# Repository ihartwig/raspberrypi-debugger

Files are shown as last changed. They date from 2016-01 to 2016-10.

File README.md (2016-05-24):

Raspberry Pi Debugger
=====================

This repository houses bare-metal hardware debugging tools for Raspberry Pi.

debugger2 3D render

## Features

* JTAG, UART, and power for RPi on single USB interface
* Supports Pi 0, 1 (Rev 2), 1+, 2 by breaking away the top section of the board when used with a Pi 1.
* Power control of RPi for system reset from UART (DTR), JTAG (sRST), and physical button
* Does not explode if RPi is powered directly (backpowering the debugger board) or both are powered at the same time independently
* Current measuring by shunt on the RPi 5V supply
* RPi HAT EEPROM footprints available but not populated
* Top SMD only design using the [RPi Foundation example SMT header](https://www.raspberrypi.org/blog/introducing-raspberry-pi-hats/) (optionally can use through hole header soldered later)

## Development Structure

* **config**: configurations for FT_Prog, OpenOCD, and GDB
* **docs**: datasheets and reference schematics this board is based on.
* **debugger**: rev 1 schematic and board in eagle
* **debugger2**: rev 2+ schematic and board in kicad
* **RPiDebuggerVCPBlock**: OS X kernel extension to allow using JTAG with serial

## Support Software

Windows and OS X users need to install the [FTDI VCP drivers](http://www.ftdichip.com/Drivers/VCP.htm). Windows may install it automatically. Linux users can use either the built or FTDI drivers. OS X (10.9+) has basic support for serial with the built in driver but does not trigger the DTR line used to control RPi power.

On OS X the VCP driver will try to assign a serial port to the FTDI channel we want to use for JTAG, preventing us from using JTAG and serial at the same time. We can fix this by installing a dummy kernel module ([suggested resolution from Apple](https://developer.apple.com/library/mac/technotes/tn2315/_index.html)), RPiDebuggerVCPBlock. Download the kext from the [relase page](https://github.com/ihartwig/raspberrypi-debugger/releases) and place it in `/Library/Extensions`. Since the kext is not signed, you must [disable kext certificate checking](http://apple.stackexchange.com/questions/163059/how-can-i-disable-kext-signing-in-mac-os-x-10-10-yosemite) in 10.10+.

To use JTAG on the RPi you need to enable the alternate pin functions in software. This can be done easily by loading the SD card with a dummy kernel that enables the JTAG interface on boot and waits.

## FTDI EEPROM

Newly assembled boards with a blank eeprom should be programmed. Functionally, this tells the windows driver to not open a com port on the FTDI channel we use for JTAG. The templates under `config` can be programmed with [FT_Prog](http://www.ftdichip.com/Support/Utilities.htm#FT_PROG).

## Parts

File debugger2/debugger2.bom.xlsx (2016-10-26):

Source | /Users/ihartwig/repos/raspberrypi-debugger/debugger2/debugger2.sch
Kicad Rev | Eeschema 4.0.0-stable
Generated Date | Wednesday | July 13 | 2016 'AMt' 02:22:38 AM
Title | Raspberry Pi Debugger
Company | Carnegie Mellon University
Revision | 2.1.2
Date Issue | Not Set
Comment | Based on FT2232H Mini Module
Comment | Drawn by: Ian Hartwig
Item # | Reference | Qty | Manufacturer | Mfg Part # | Description | Footprint | Type | Link | Value | Library | Library Ref
1 | C1, C2, C3, C4, C6, C7, C9, C12, C13, C16, C18 | 11 | Murata | GRM188R71C104KA01D | CAP CER 0.1uF ±10% 16V X7R 0603 | Capacitors_SMD:C_0603 | SMT |  | 100n | device | C_Small
2 | C17, C19 | 2 | Murata | GRM1885C1H180JA01D | CAP CER 18PF ±5% 50V NP0 0603 | Capacitors_SMD:C_0603 | SMT |  | 18pF | device | C_Small
3 | C20, C21 | 2 | Murata | GRM188R71C105KE15D | CAP CER 1UF ±10% 16V X7R 0603 | Capacitors_SMD:C_0603 | SMT |  | 1uF | device | C_Small
4 | C22 | 1 | Murata | GRM188R71C104KA01D | CAP CER 0.1uF ±10% 16V X7R 0603 | Capacitors_SMD:C_0603 | DNS |  | dnp-100n | device | C_Small
5 | C5, C8, C11, C14, C15 | 5 | AVX | 1206YG475ZAT2A | CAP CER 4.7UF -20% ~ + 80% 16V Y5V 1206 | Capacitors_SMD:C_1206 | SMT |  | 4.7u | device | CP1_Small
6 | D1, D2, D3 | 3 | Lite-On | LTST-C190GKT | LED GREEN CLEAR 0603 SMD | LEDs:LED-0603 | SMT | http://www.digikey.com/product-detail/en/LTST-C190GKT/160-1183-1-ND/269255 | RXLED | device | Led_Small
7 | D4, D5 | 2 | Panasonic | DB2S20500L | DIODE SCHOTTKY 15V 200MA SSMINI2 | Diodes_SMD:SOD-523 | SMT | http://www.digikey.com/product-detail/en/panasonic-electronic-components/DB2S20500L/DB2S20500LCT-ND/2326091 | D_Small | device | D_Small
8 | FB1, FB2 | 2 | Samsung | CIM21J202NE | FERRITE BEAD 2 KOHM 0805 | Resistors_SMD:R_0805 | SMT | http://www.digikey.com/product-detail/en/CIM21J202NE/1276-6330-1-ND/3973845 | 600R/0.5A | device | L_Small
9 | P1 | 1 |  |  |  | Pin_Headers:Pin_Header_Straight_1x02 | DNS |  | CONN_01X01 | conn | CONN_01X01
10 | P3 | 1 | Amphenol-FCI | 10118192-0001LF | USB - micro B USB 2.0 Receptacle Connector 5 Position Surface Mount, Right Angle, Horizontal | debugger2-special:USB_Micro-B_SMT | SMT | http://www.digikey.com/product-detail/en/amphenol-fci/10118192-0001LF/609-4613-1-ND/2785378 | USB_OTG | conn | USB_OTG
11 | P4 | 1 | Samtec | REF-182665-01 | 2x20 pos. with PCB alignment peg option | debugger2-special:Pin_Header_Straight_TH-SMT_2x20 | DNS | http://www.toby.co.uk/content/catalogue/products.aspx?series=REF-1826xx-0x | CONN_02X20 | conn | CONN_02X20 | Can also use Harwin M20-6102045 (Digikey 952-2219-ND) for bottom TH.
12 | P5 | 1 |  |  |  | Pin_Headers:Pin_Header_Straight_1x02 | DNS |  | dnp-CONN_01X02 | conn | CONN_01X02
13 | Q1 | 1 | Diodes Inc | DMP3099L-7 | MOSFET P-CH 30V SOT23 | TO_SOT_Packages_SMD:SOT-23 | SMT | http://www.digikey.com/product-detail/en/DMP3099L-7/DMP3099L-7DICT-ND/5218217 | Q_PMOS_GSD | device | Q_PMOS_GSD
14 | Q2 | 1 | Diodes Inc | DMMT3906-7-F | TRANS 2PNP 40V 0.2A SOT26 | TO_SOT_Packages_SMD:SOT-23-6 | SMT | http://www.digikey.com/product-detail/en/DMMT3906-7-F/DMMT3906-7-FDICT-ND/2242785 | DMMT3906_Dual_PNP | debugger2-special | DMMT3906_Dual_PNP
15 | R1, R6, R8, R13, R19 | 5 | Vishay Dale | CRCW060310K0FKEA | RES SMD 10K OHM 1% 1/10W 0603 | Resistors_SMD:R_0603 | SMT |  | 10k | device | R_Small
16 | R11, R12 | 2 | Vishay Dale | CRCW060310R0FKEA | RES SMD 10 OHM 1% 1/10W 0603 | Resistors_SMD:R_0603 | SMT |  | 10 | device | R
17 | R14 | 1 | Vishay Dale | CRCW060347K0FKEA | RES SMD 47K OHM 1% 1/10W 0603 | Resistors_SMD:R_0603 | SMT | http://www.digikey.com/product-detail/en/vishay-dale/CRCW060347K0FKEA/541-47.0KHCT-ND/1180000 | 47k | device | R_Small
18 | R16 | 1 | Vishay Dale | CRCW06031K00FKEA | RES SMD 1K OHM 1% 1/10W 0603 | Resistors_SMD:R_0603 | DNS |  | dnp-1k | device | R_Small
19 | R17, R18 | 2 | Vishay Dale | CRCW06033K90FKEA | RES SMD 3.9K OHM 1% 1/10W 0603 | Resistors_SMD:R_0603 | DNS |  | dnp-3.9k | device | R_Small
20 | R2 | 1 | Vishay Dale | CRCW06032K00FKEA | RES SMD 2K OHM 1% 1/10W 0603 | Resistors_SMD:R_0603 | SMT |  | 2k | device | R_Small
21 | R3 | 1 | Vishay Dale | CRCW060320K0FKEA | RES SMD 20K OHM 1% 1/10W 0603 | Resistors_SMD:R_0603 | SMT |  | 20k | device | R_Small
22 | R4 | 1 | Vishay Dale | CRCW060333K0FKEA | RES SMD 33K OHM 1% 1/10W 0603 | Resistors_SMD:R_0603 | SMT |  | 33k | device | R_Small
23 | R5 | 1 |  |  |  | Resistors_SMD:R_0603 | DNS |  | dnp-0 | device | R
24 | R7 | 1 | Stackpole Electronics | CSR1206FT50L0 | RES SMD 0.05 OHM 1% 1/2W 1206 | Resistors_SMD:R_1206 | SMT | http://www.digikey.com/product-detail/en/stackpole-electronics-inc/CSR1206FT50L0/CSR1206FT50L0CT-ND/3477072 | 0.01 | device | R
25 | R9, R10, R15 | 3 | Vishay Dale | CRCW0603220RFKEA | RES SMD 220 OHM 1% 1/10W 0603 | Resistors_SMD:R_0603 | SMT | http://www.digikey.com/product-detail/en/vishay-dale/CRCW0603220RFKEA/541-220HCT-ND/1179731 | 220 | device | R_Small
26 | SW1 | 1 | TE Connectivity | FSMCTTR | SWITCH TACTILE SPST-NO 0.02A 15V | Buttons_Switches_SMD:SW_SPST_EVPBF | SMT | http://www.digikey.com/product-detail/en/FSMCTTR/450-2133-1-ND/5343813 | SW_PUSH | device | SW_PUSH
27 | U1 | 1 | Microchip | 93LC56B-I/ST | IC EEPROM 2KBIT 2MHZ 8TSSOP | Housings_SSOP:TSSOP-8_4.4x3mm_Pitch0.65mm | SMT | http://www.digikey.com/product-detail/en/93LC56B-I%2FST/93LC56B-I%2FST-ND/319187 | 93LC56B | memory | 93LCxxA
28 | U2 | 1 | Microchip | MIC94092YC6-TR | IC LOAD SW HGH SIDE 1.2A SC70-6 | TO_SOT_Packages_SMD:SC-70-6 | SMT | http://www.digikey.com/product-detail/en/microchip-technology/MIC94092YC6-TR/576-3488-1-ND/2062485 | MIC94092_SC-70 | debugger2-special | MIC94092_SC-70
29 | U3 | 1 | FTDI | FT2232HL | IC USB HS DUAL UART/FIFO 64-LQFP | Housings_QFP:TQFP-64_10x10mm_Pitch0.5mm | SMT | http://www.digikey.com/product-detail/en/FT2232HL-REEL/768-1024-1-ND/1986057 | FT2232HL | debugger2-special | FT2232HL
30 | U4 | 1 | Diodes Inc | AP7365-33WG-7 | IC REG LDO 3.3V 0.6A SOT-25 | TO_SOT_Packages_SMD:SOT-23-5 | SMT | http://www.digikey.com/product-detail/en/AP7365-33WG-7/AP7365-33WG-7DICT-ND/5267107 | AP7365_SOT-23-5 | debugger2-special | AP7365_SOT-23-5
31 | U5 | 1 | NXP | PRTR5V0U2X,215 | TVS DIODE 5.5VWM SOT143B | debugger2-special:SOT-143_NXP | SMT | http://www.digikey.com/product-detail/en/PRTR5V0U2X,215/568-4140-1-ND/1589981 | PRTR5V0U2X | debugger2-special | PRTR5V0U2X
32 | U6 | 1 |  |  |  | Housings_SSOP:TSSOP-8_4.4x3mm_Pitch0.65mm | DNS |  | dnp-AT24CS32-SSHM | memory | AT24CS32-SSHM
33 | Y1 | 1 | Abracon LLC | ABM8-12.000MHZ-B2-T | 12MHz ±20ppm Crystal 18pF 120 Ohm -20°C ~ 70°C Surface Mount 4-SMD, No Lead (DFN, LCC) | debugger2-special:Crystal_Grounded_3.2x2.5 | SMT | http://www.digikey.com/product-detail/en/ABM8-12.000MHZ-B2-T/535-9826-1-ND/2001449 | 12MHz | device | CRYSTAL_SMD

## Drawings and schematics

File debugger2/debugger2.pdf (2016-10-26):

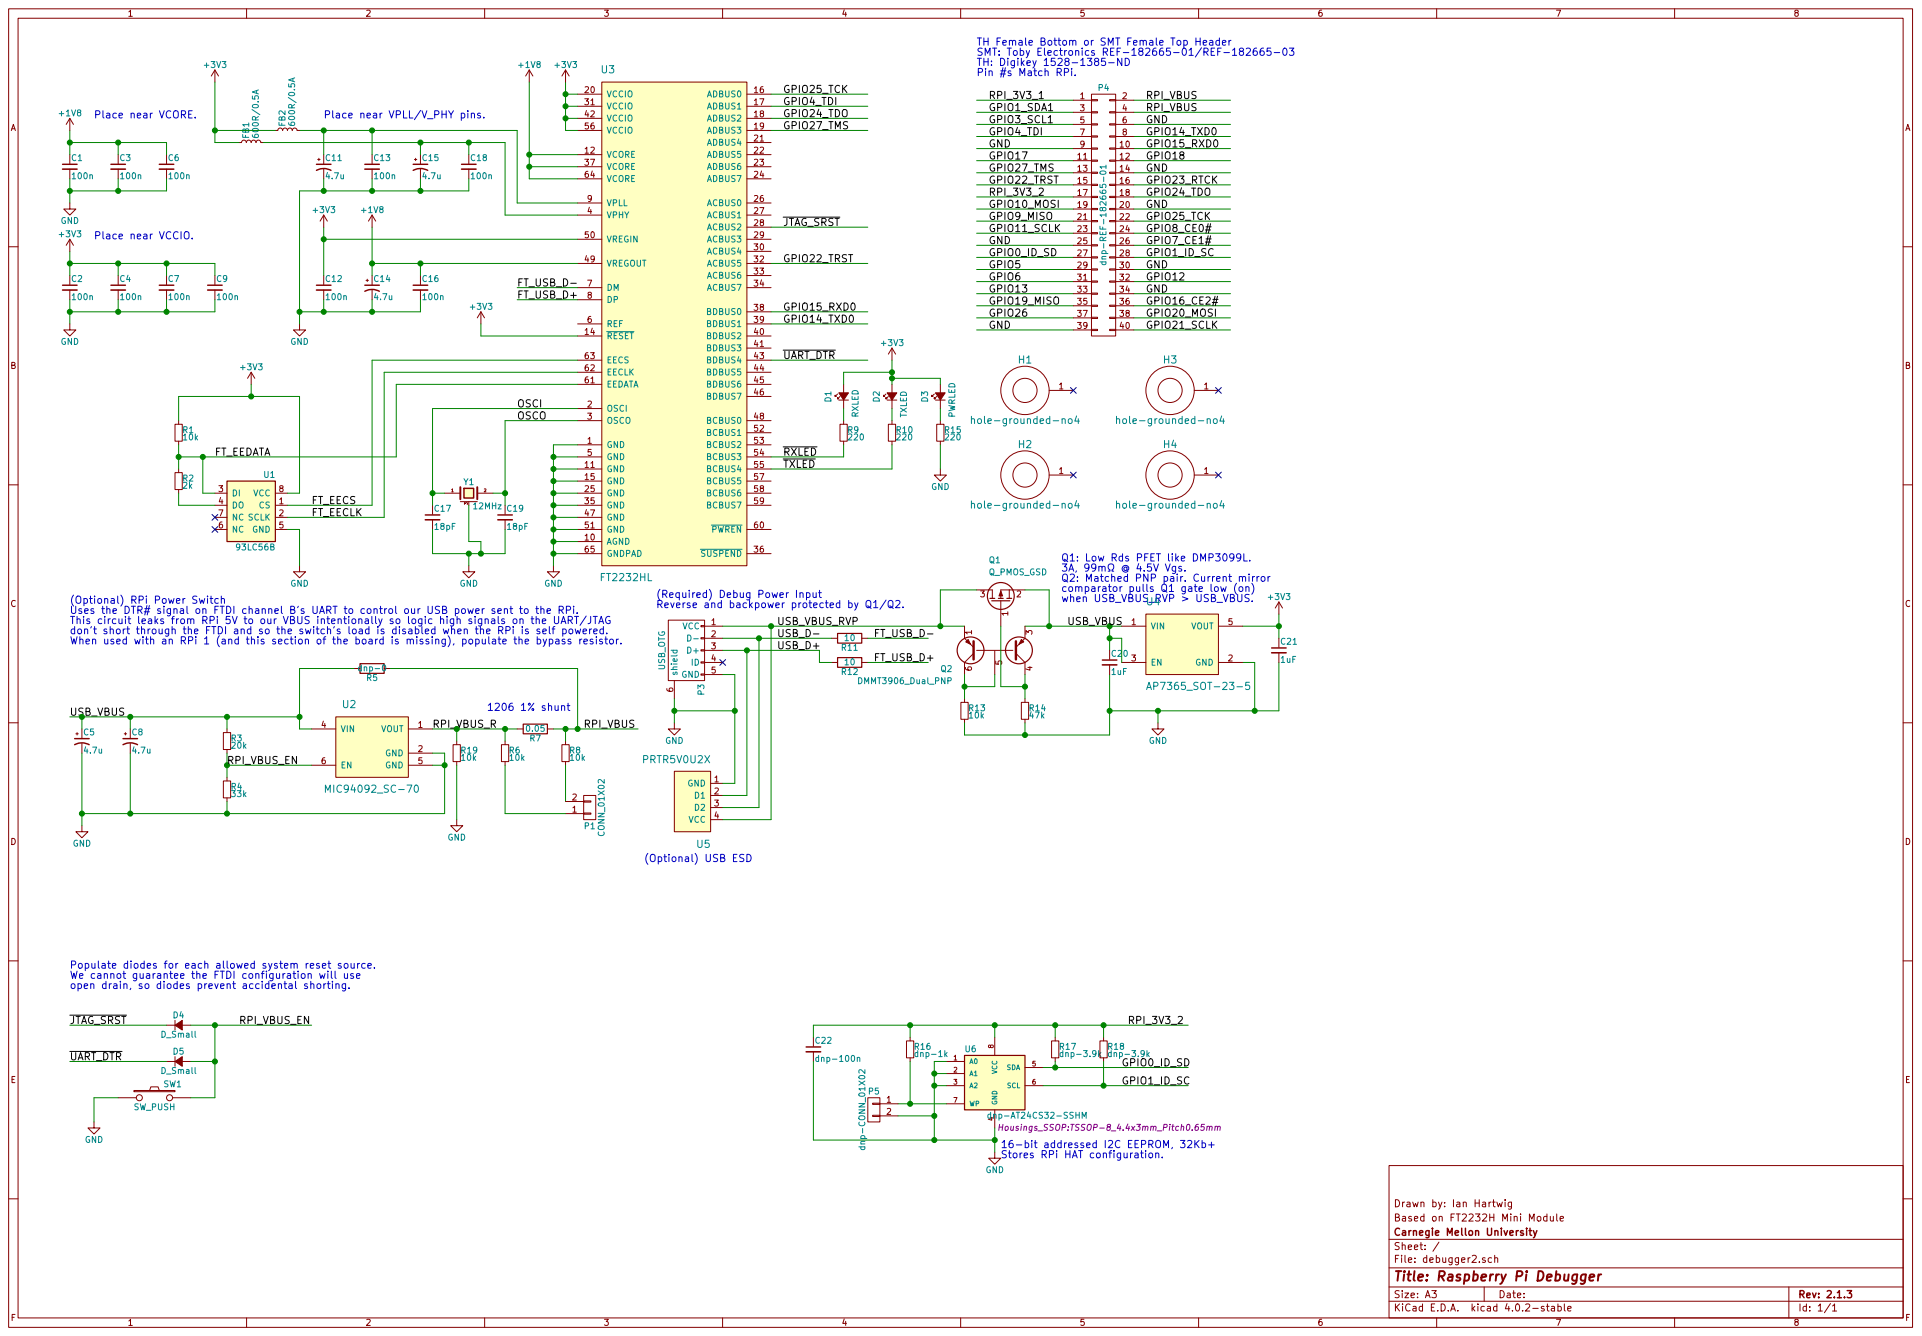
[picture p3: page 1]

TH Female Bottom or SMT Female Top Header
SMT: Toby Electronics REF-182665-01/REF-182665-03
TH: Digikey 1528-1385-ND

GPIO4_TDI
GPIO24_TDO
GPIO27_TMS

When used with an RPi 1 (and this section of the board is missing), populate the bypass resistor. R1

Q1: Low Rds PFET like DMP3099L.
3A, 99m @ 4.5V Vgs.
Q2: Matched PNP pair. Current mirror
comparator pulls Q1 gate low (on)

(Optional) RPi Power Switch
Uses the DTR# signal on FTDI channel B's UART to control our USB power sent to the RPi.
This circuit leaks from RPi 5V to our VBUS intentionally so logic high signals on the UART/JTAG
don't short through the FTDI and so the switch's load is disabled when the RPi is self powered.

(Required) Debug Power Input
Reverse and backpower protected by Q1/Q2.

Populate diodes for each allowed system reset source.
We cannot guarantee the FTDI configuration will use

File: debugger2.sch Sheet: / Carnegie Mellon University Based on FT2232H Mini Module Drawn by: Ian Hartwig

Id: 1/1 Title: Raspberry Pi Debugger

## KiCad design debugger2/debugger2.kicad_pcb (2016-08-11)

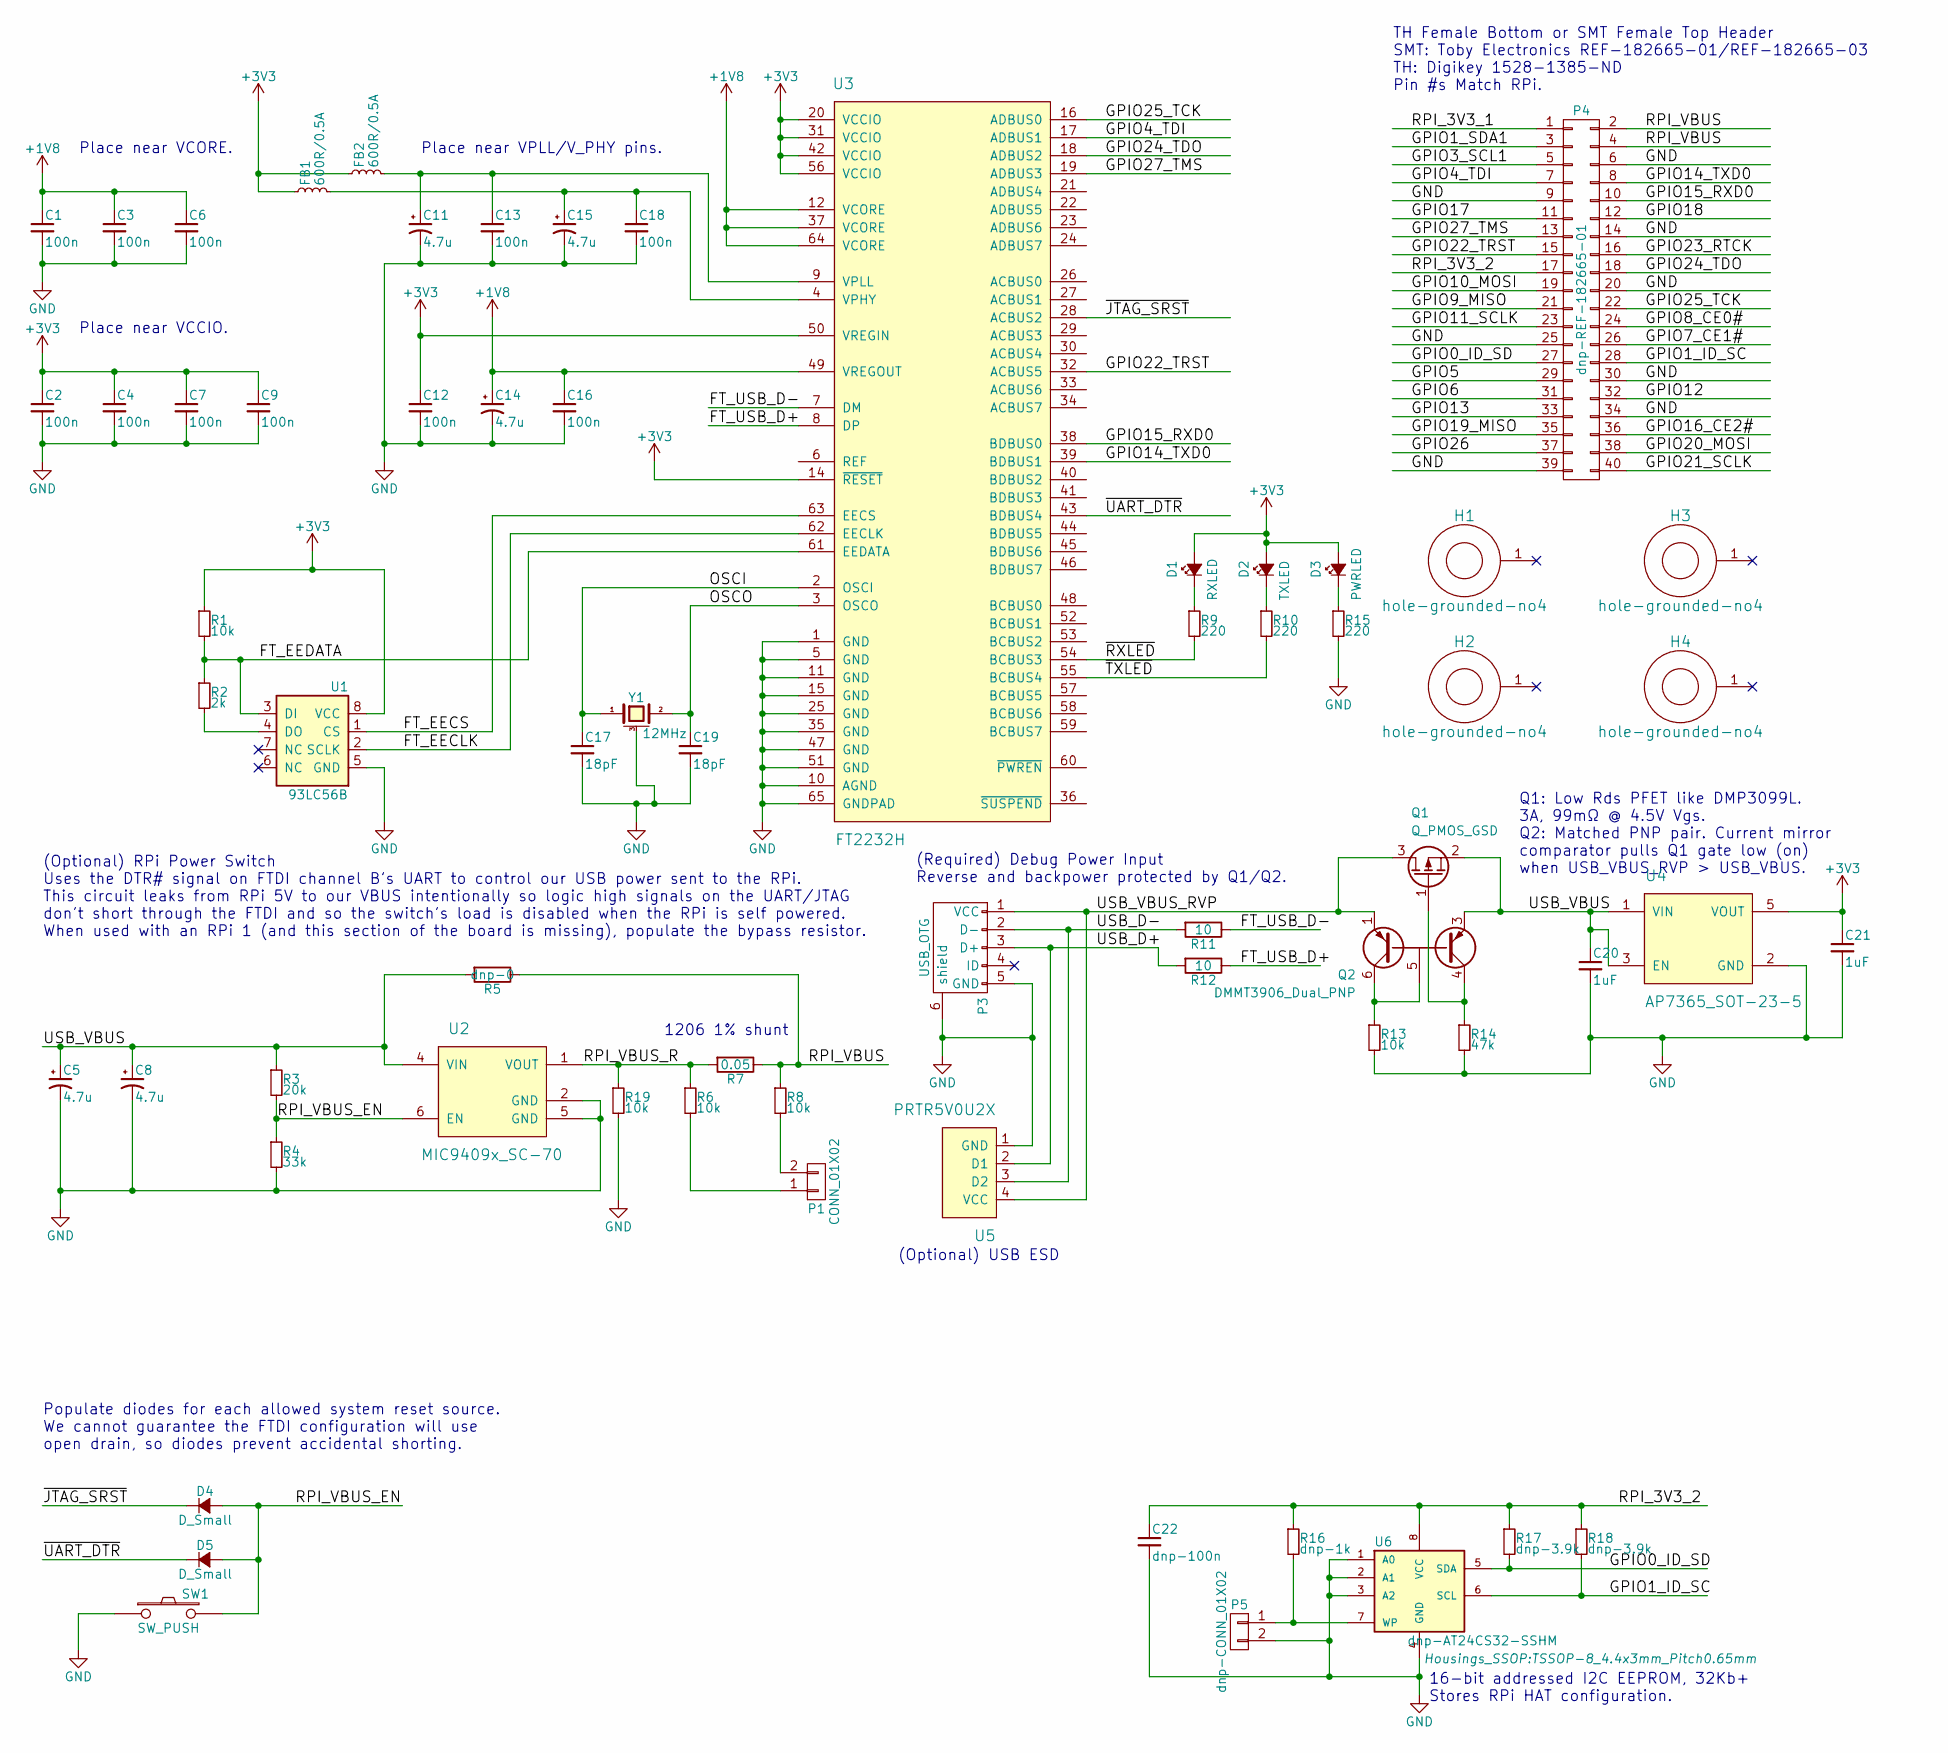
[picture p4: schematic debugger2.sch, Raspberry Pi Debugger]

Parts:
C1, C2, C3, C4, C6, C7, C9, C12, C13, C16, C18: 100n; C_0603
C5, C8, C11, C14, C15: 4.7u; C_1206
C17, C19: 18pF; C_0603
C20, C21: 1uF; C_0603
C22: dnp-100n; C_0603
D1: RXLED; LED-0603
D2: TXLED; LED-0603
D3: PWRLED; LED-0603
D4, D5: D_Small; SOD-523
FB1, FB2: 600R/0.5A; R_0805
H1, H2, H3, H4: hole-grounded-no4; hole-no4
P1: CONN_01X02; Pin_Header_Straight_1x02
P3: USB_OTG; USB_Micro-B_SMT
P4: dnp-REF-182665-01; Pin_Header_Straight_TH-SMT-NoPaste_2x20
P5: dnp-CONN_01X02; Pin_Header_Straight_1x02
Q1: Q_PMOS_GSD; SOT-23
Q2: DMMT3906_Dual_PNP; SOT-23-6
R1, R6, R8, R13, R19: 10k; R_0603
R2: 2k; R_0603
R3: 20k; R_0603
R4: 33k; R_0603
R5: dnp-0; R_0603
R7: 0.05; R_1206
R9, R10, R15: 220; R_0603
R11, R12: 10; R_0603
R14: 47k; R_0603
R16: dnp-1k; R_0603
R17, R18: dnp-3.9k; R_0603
SW1: SW_PUSH; SW_SPST_EVPBF
U1: 93LC56B; TSSOP-8_4.4x3mm_Pitch0.65mm
U2: MIC9409x_SC-70; SC-70-6
U3: FT2232H; TQFP-64_10x10mm_Pitch0.5mm
U4: AP7365_SOT-23-5; SOT-23-5
U5: PRTR5V0U2X; SOT-143_NXP
U6: dnp-AT24CS32-SSHM; TSSOP-8_4.4x3mm_Pitch0.65mm
Y1: 12MHz; Crystal_Grounded_3.2x2.5

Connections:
+1V8: C1.1, C3.1, C6.1, C14.1, C16.1, U3.12 (VCORE), U3.37 (VCORE), U3.49 (VREGOUT), U3.64 (VCORE)
+3V3: C2.1, C4.1, C7.1, C9.1, C12.1, C21.1, D1.2 (A), D2.2 (A), D3.2 (A), FB1.1, FB2.1, R1.1, U1.8 (VCC), U3.14 (~RESET), U3.20 (VCCIO), U3.31 (VCCIO), U3.42 (VCCIO), U3.50 (VREGIN), U3.56 (VCCIO), U4.5 (VOUT)
/FT_EECLK: U1.2 (SCLK), U3.62 (EECLK)
/FT_EECS: U1.1 (CS), U3.63 (EECS)
/FT_EEDATA: R1.2, R2.1, U1.3 (DI), U3.61 (EEDATA)
/FT_USB_D+: R12.1, U3.8 (DP)
/FT_USB_D-: R11.1, U3.7 (DM)
/GPIO0_ID_SD: P4.27, R17.2, U6.5 (SDA)
/GPIO1_ID_SC: P4.28, R18.2, U6.6 (SCL)
/GPIO1_SDA1: P4.3
/GPIO3_SCL1: P4.5
/GPIO4_TDI: P4.7, U3.17 (ADBUS1)
/GPIO5: P4.29
/GPIO6: P4.31
/GPIO7_CE1#: P4.26
/GPIO8_CE0#: P4.24
/GPIO9_MISO: P4.21
/GPIO10_MOSI: P4.19
/GPIO11_SCLK: P4.23
/GPIO12: P4.32
/GPIO13: P4.33
/GPIO14_TXD0: P4.8, U3.39 (BDBUS1)
/GPIO15_RXD0: P4.10, U3.38 (BDBUS0)
/GPIO16_CE2#: P4.36
/GPIO17: P4.11
/GPIO18: P4.12
/GPIO19_MISO: P4.35
/GPIO20_MOSI: P4.38
/GPIO21_SCLK: P4.40
/GPIO22_TRST: P4.15, U3.32 (ACBUS5)
/GPIO23_RTCK: P4.16
/GPIO24_TDO: P4.18, U3.18 (ADBUS2)
/GPIO25_TCK: P4.22, U3.16 (ADBUS0)
/GPIO26: P4.37
/GPIO27_TMS: P4.13, U3.19 (ADBUS3)
/OSCI: C17.1, U3.2 (OSCI), Y1.1
/OSCO: C19.1, U3.3 (OSCO), Y1.2
/RPI_3V3_1: P4.1
/RPI_3V3_2: C22.1, P4.17, R16.1, R17.1, R18.1, U6.8 (VCC)
/RPI_VBUS: P4.2, P4.4, R5.1, R7.1, R8.1
/RPI_VBUS_EN: D4.2 (A), D5.2 (A), R3.2, R4.1, SW1.2, U2.6 (EN)
/RPI_VBUS_R: R6.1, R7.2, R19.1, U2.1 (VOUT)
/USB_D+: P3.3 (D+), R12.2, U5.2 (D1)
/USB_D-: P3.2 (D-), R11.2, U5.3 (D2)
/USB_VBUS: C5.1, C8.1, C20.1, Q1.2 (S), Q2.3 (E2), R3.1, R5.2, U2.4 (VIN), U4.1 (VIN), U4.3 (EN)
/USB_VBUS_RVP: P3.1 (VCC), Q1.3 (D), Q2.1 (E1), U5.4 (VCC)
/~JTAG_SRST: D4.1 (K), U3.28 (ACBUS2)
/~RXLED: R9.2, U3.54 (BCBUS3)
/~TXLED: R10.2, U3.55 (BCBUS4)
/~UART_DTR: D5.1 (K), U3.43 (BDBUS4)
GND: C1.2, C2.2, C3.2, C4.2, C5.2, C6.2, C7.2, C8.2, C9.2, C11.2, C12.2, C13.2, C14.2, C15.2, C16.2, C17.2, C18.2, C19.2, C20.2, C21.2, C22.2, P3.5 (GND), P3.6 (shield), P4.6, P4.9, P4.14, P4.20, P4.25, P4.30, P4.34, P4.39, P5.2, R4.2, R13.2, R14.2, R15.2, R19.2, SW1.1, U1.5 (GND), U2.2 (GND), U2.5 (GND), U3.1 (GND), U3.5 (GND), U3.10 (AGND), U3.11 (GND), U3.15 (GND), U3.25 (GND), U3.35 (GND), U3.47 (GND), U3.51 (GND), U3.65 (GNDPAD), U4.2 (GND), U5.1 (GND), U6.1 (A0), U6.2 (A1), U6.3 (A2), U6.4 (GND), Y1.3 (case)
unnamed: C11.1, C13.1, FB2.2, U3.9 (VPLL)
unnamed: C15.1, C18.1, FB1.2, U3.4 (VPHY)
unnamed: D1.1 (K), R9.1
unnamed: D2.1 (K), R10.1
unnamed: D3.1 (K), R15.1
unnamed: P1.1, R6.2
unnamed: P1.2, R8.2
unnamed: P5.1, R16.2, U6.7 (WP)
unnamed: Q1.1 (G), Q2.4 (C2), R14.1
unnamed: Q2.5 (B), Q2.6 (C1), R13.1
unnamed: R2.2, U1.4 (DO)

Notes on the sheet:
Place near VCCIO.
Place near VCORE.
(Optional) RPi Power Switch Uses the DTR# signal on FTDI channel B's UART to control our USB power sent to the RPi. This circuit leaks from RPi 5V to our VBUS intentionally so logic high signals on the UART/JTAG don't short through the FTDI and so the switch's load is disabled when the RPi is self 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
TH Female Bottom or SMT Female Top Header SMT: Toby Electronics REF-182665-01/REF-182665-03 TH: Digikey 1528-1385-ND Pin #s Match RPi.
1206 1% shunt
(Required) Debug Power Input Reverse and backpower protected by Q1/Q2.
Q1: Low Rds PFET like DMP3099L. 3A, 99mΩ @ 4.5V Vgs. Q2: Matched PNP pair. Current mirror comparator pulls Q1 gate low (on) when USB_VBUS_RVP > USB_VBUS.
Place near VPLL/V_PHY pins.
(Optional) USB ESD
16-bit addressed I2C EEPROM, 32Kb+ Stores RPi HAT configuration.
Populate diodes for each allowed system reset source. We cannot guarantee the FTDI configuration will use open drain, so diodes prevent accidental shorting.

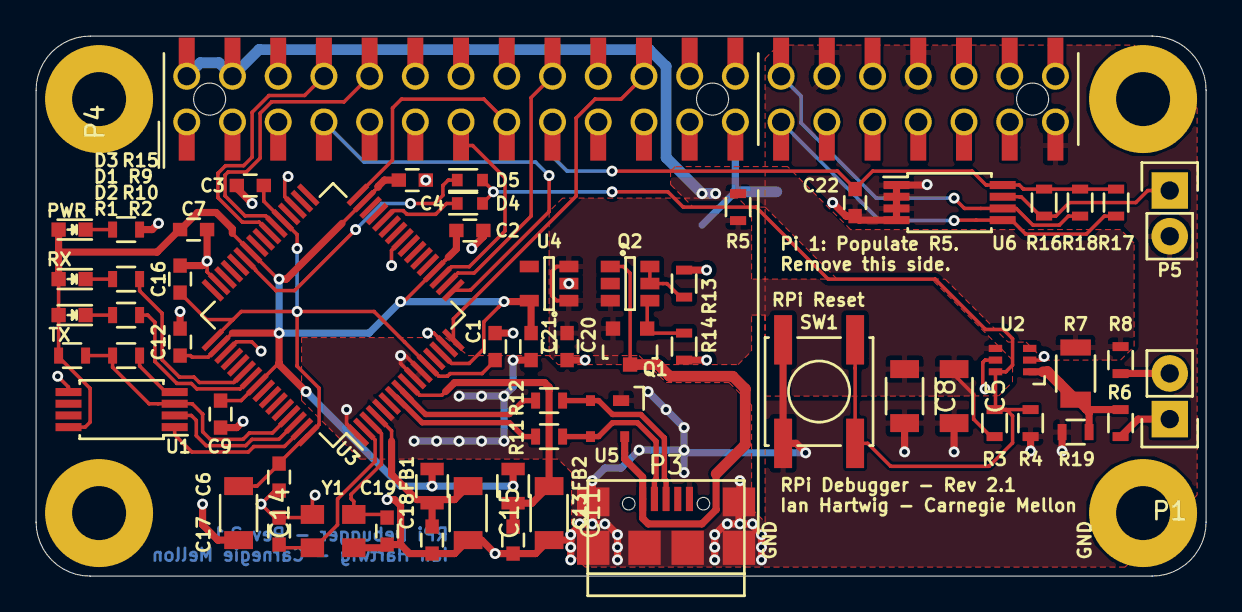
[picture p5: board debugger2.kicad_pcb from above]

Board: 2 copper layers, 65.0 x 30.0 mm, 65 parts (0 on the bottom side), 42 nets.

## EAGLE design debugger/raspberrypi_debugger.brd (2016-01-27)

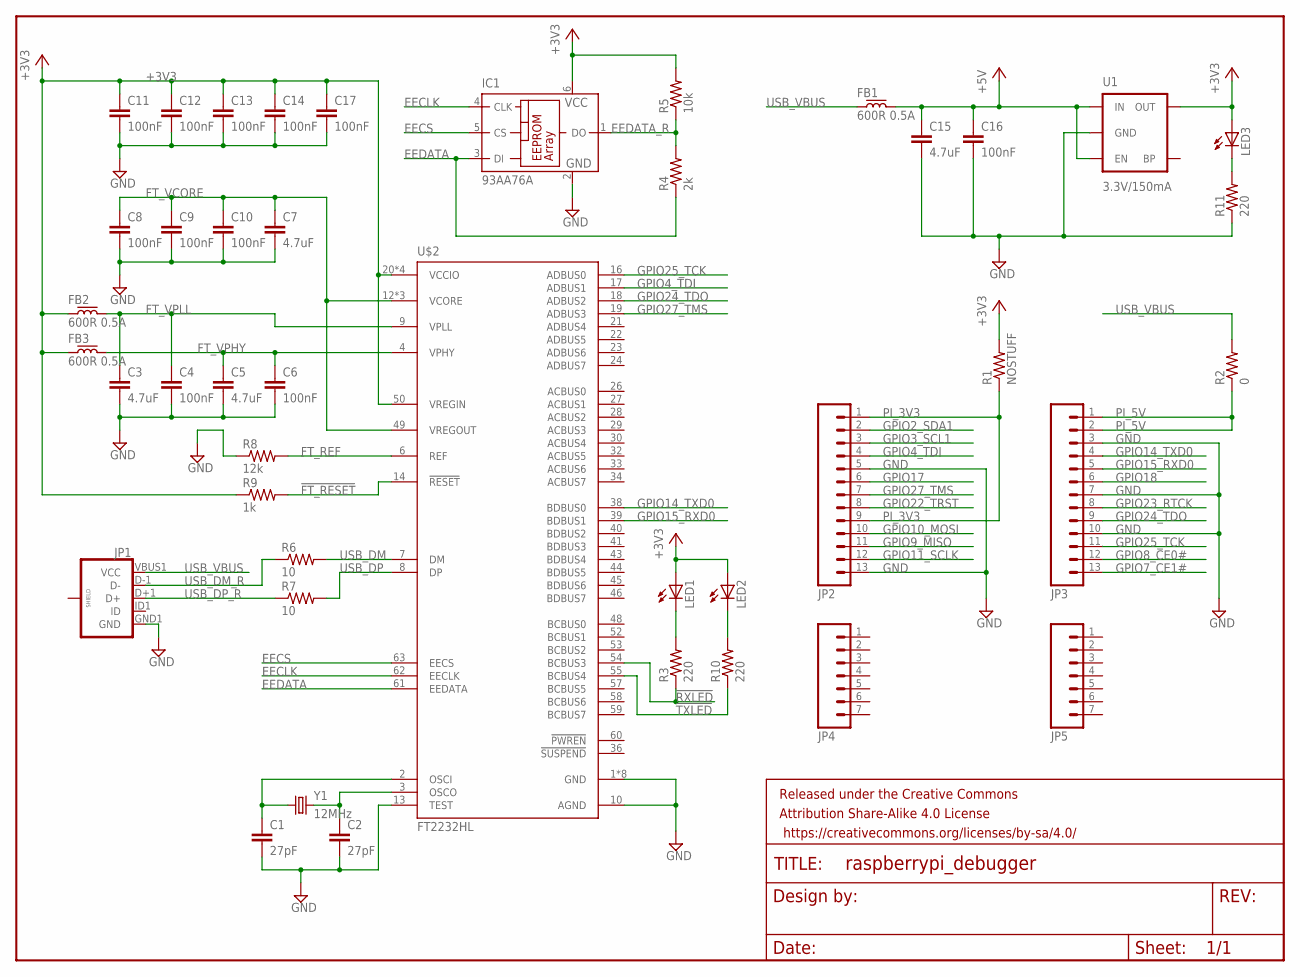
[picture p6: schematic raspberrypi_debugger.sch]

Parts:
C1, C2: 27pF; C0805
C3, C5, C7, C15: 4.7uF; C1206
C4, C6, C8, C9, C10, C11, C12, C13, C14, C16, C17: 100nF; C0805
FB1, FB2, FB3: 600R 0.5A; R0805
FRAME1: FRAME-LETTERNO_PACKAGE; DUMMY
IC1: 93AA76A; SOT23-6
JP1: USB_MICROB_PLUGCONN-11752; USB-B-MICRO-SMD_V03
JP2, JP3: M13LOCK; 1X13_LOCK
JP4, JP5: M07LOCK; 1X07_LOCK
LED1, LED2, LED3: LEDCHIP-LED0805; CHIP-LED0805
R1: NOSTUFF; R0805
R2: 0; R0805
R3, R10, R11: 220; R0805
R4: 2k; R0805
R5: 10k; R0805
R6, R7: 10; R0805
R8: 12k; R0805
R9: 1k; R0805
U1: 3.3V/150mA; SOT23-5
U$2: FT2232HL; TQFP64-10X10
Y1: 12MHz; HC49UP

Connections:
!FT_RESET: R9.2, U$2.14 (!RESET)
!RXLED: R3.1, U$2.54 (BCBUS3)
!TXLED: R10.1, U$2.55 (BCBUS4)
+3V3: C11.1, C12.1, C13.1, C14.1, C17.1, FB2.2, FB3.2, IC1.6 (VCC), LED1.A, LED2.A, LED3.A, R1.2, R5.2, R9.1, U1.5 (OUT), U$2.20 (VCCIO), U$2.31 (VCCIO), U$2.42 (VCCIO), U$2.50 (VREGIN), U$2.56 (VCCIO)
+5V: C15.1, C16.1, FB1.1, U1.1 (IN), U1.3 (EN)
EECLK: IC1.4 (CLK), U$2.62 (EECLK)
EECS: IC1.5 (CS), U$2.63 (EECS)
EEDATA: IC1.3 (DI), R4.1, U$2.61 (EEDATA)
EEDATA_R: IC1.1 (DO), R4.2, R5.1
FT_REF: R8.2, U$2.6 (REF)
FT_VCORE: C7.1, C8.1, C9.1, C10.1, U$2.12 (VCORE), U$2.37 (VCORE), U$2.49 (VREGOUT), U$2.64 (VCORE)
FT_VPHY: C5.1, C6.1, FB3.1, U$2.4 (VPHY)
FT_VPLL: C3.1, C4.1, FB2.1, U$2.9 (VPLL)
GND: C1.2, C2.2, C3.2, C4.2, C5.2, C6.2, C7.2, C8.2, C9.2, C10.2, C11.2, C12.2, C13.2, C14.2, C15.2, C16.2, C17.2, IC1.2 (GND), JP1.GND1 (GND), JP2.5, JP2.13, JP3.3, JP3.7, JP3.10, R8.1, R11.1, U1.2 (GND), U$2.1 (GND), U$2.5 (GND), U$2.10 (AGND), U$2.11 (GND), U$2.13 (TEST), U$2.15 (GND), U$2.25 (GND), U$2.35 (GND), U$2.47 (GND), U$2.51 (GND)
GPIO2_SDA1: JP2.2
GPIO3_SCL1: JP2.3
GPIO4_TDI: JP2.4, U$2.17 (ADBUS1)
GPIO7_CE1#: JP3.13
GPIO8_CE0#: JP3.12
GPIO9_MISO: JP2.11
GPIO10_MOSI: JP2.10
GPIO11_SCLK: JP2.12
GPIO14_TXD0: JP3.4, U$2.38 (BDBUS0)
GPIO15_RXD0: JP3.5, U$2.39 (BDBUS1)
GPIO17: JP2.6
GPIO18: JP3.6
GPIO22_TRST: JP2.8
GPIO23_RTCK: JP3.8
GPIO24_TDO: JP3.9, U$2.18 (ADBUS2)
GPIO25_TCK: JP3.11, U$2.16 (ADBUS0)
GPIO27_TMS: JP2.7, U$2.19 (ADBUS3)
unnamed: C1.1, U$2.2 (OSCI), Y1.1
unnamed: C2.1, U$2.3 (OSCO), Y1.2
unnamed: LED1.C, R3.2
unnamed: LED2.C, R10.2
unnamed: LED3.C, R11.2
PI_3V3: JP2.1, JP2.9, R1.1
PI_5V: JP3.1, JP3.2, R2.1
USB_DM: R6.2, U$2.7 (DM)
USB_DM_R: JP1.D-1 (D-), R6.1
USB_DP: R7.2, U$2.8 (DP)
USB_DP_R: JP1.D+1 (D+), R7.1
USB_VBUS: FB1.2, JP1.VBUS1 (VCC), R2.2

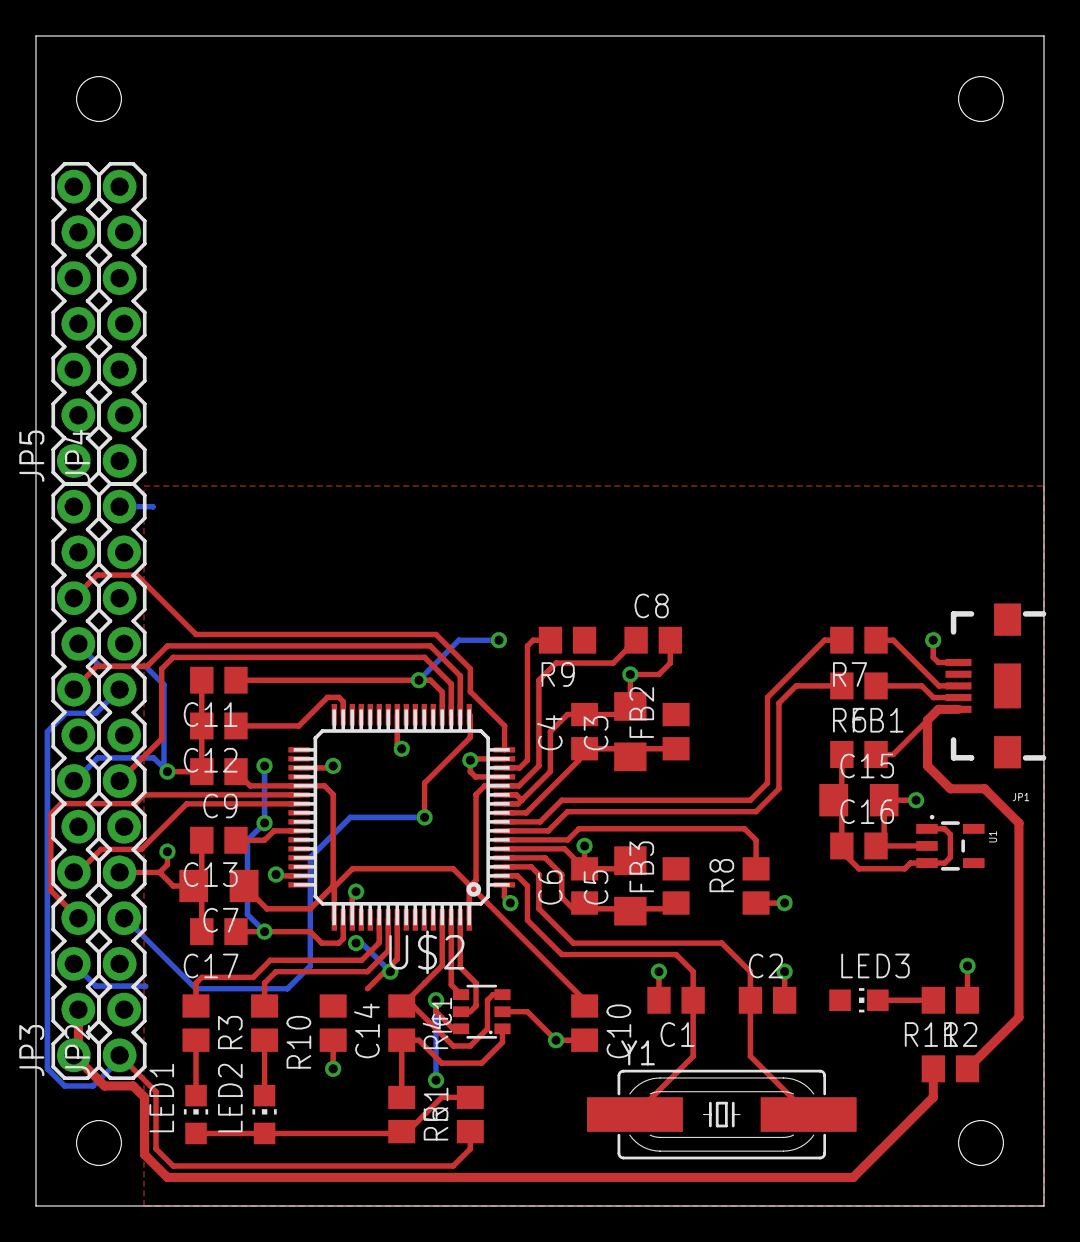
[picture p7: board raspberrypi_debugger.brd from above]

Board: 2 copper layers, 56.0 x 65.0 mm, 44 parts (0 on the bottom side), 32 nets.

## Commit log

2016-01-27 initial schematic and routing for Pi 1, 2
    [raspberrypi_debugger.brd, raspberrypi_debugger.sch]
2016-02-01 schematic and routing for debugger2
    [debugger2.kicad_pcb, debugger2.sch]
2016-02-02 update board layout for 6/6mil (was 5/5mil)
    [debugger2.kicad_pcb]
2016-02-02 add debugger2 gerbers
    [debugger2-B.Cu.gbl, debugger2-B.Mask.gbs, debugger2-B.Paste.gbp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]
2016-02-02 add debugger2 schematic in pdf
    [debugger2.kicad_pcb, debugger2.sch]
2016-03-16 update bom information
    [debugger2.bom.xlsx]
2016-04-30 rev 2.1 fixes for UART, JTAG resets, EEPROM packages
    * fix UART (FTDI Ch B) RX/TX backwards
    * fix GPIO22_TRST floating by connecting to FTDI Ch A. in debugger 1 we pulled up to 3.3V, but this gives us software control of tap reset
    * add options to control RPi power (reset) from FTDI Ch A and button. diodes can be left off BOM to disable a source
    * add external drain resistor for vbus switch (backpowering from rpi can cause fet drain in the switch to magic smoke)
    * add grounding pad for probe clips
    * make holes floating so we can use metal standoffs
    * make FB1, FB2 be 0805 (not available in 0603)
    * make both EEPROMs TSSOP for easier purchasing (but not compatible)
    * reroute USB to a shorter p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
    [debugger2-B.Cu.gbl, debugger2-B.Mask.gbs, debugger2-B.Paste.gbp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]
2016-05-06 rev 2.1.1 swap usb micro b to SMT version since many board houses can't make the slots
    [debugger2-B.Cu.gbl, debugger2-B.Mask.gbs, debugger2-B.Paste.gbp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]
2016-05-12 rename eagle to debugger to reflect first generation hardware
    [raspberrypi_debugger.brd, raspberrypi_debugger.sch]
2016-05-24 update readme with build and installation info
    [rpi-debugger2.cfg]
2016-07-11 rev 2.1.2 swap tantalum caps for ceramic, 2:1 aspect vias
    [debugger2-B.Cu.gbl, debugger2-B.Mask.gbs, debugger2-B.Paste.gbp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]
2016-07-13 rev 2.1.3 combine P1 and P2, update BOM, make R3 possible value
    [debugger2-B.Cu.gbl, debugger2-B.Mask.gbs, debugger2-B.Paste.gbp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]
2016-07-18 change shunt resistor to 0.05 ohm
    [debugger2.bom.xlsx, debugger2.sch]
2016-08-11 swap rpi connector for no paste verison and no stuff
    [debugger2-B.Cu.gbl, debugger2-B.Mask.gbs, debugger2-B.Paste.gbp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]
2016-08-11 fix missing Y1 in position file by adding INSERT footprint attribute
    [debugger2-all.pos.csv]
2016-10-19 update U2 and U3 part no on bom and schematic. prevents U2 smoking
    [debugger2.bom.xlsx, debugger2.sch]
2016-10-26 fix D4 D5 part in bom for mismatched footprint, change sch paper size so we plot everything
    [debugger2.bom.xlsx, debugger2.sch]

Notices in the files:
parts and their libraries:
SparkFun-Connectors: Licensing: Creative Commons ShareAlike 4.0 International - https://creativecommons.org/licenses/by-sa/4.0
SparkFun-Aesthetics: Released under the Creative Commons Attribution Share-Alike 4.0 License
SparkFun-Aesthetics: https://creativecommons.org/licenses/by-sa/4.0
